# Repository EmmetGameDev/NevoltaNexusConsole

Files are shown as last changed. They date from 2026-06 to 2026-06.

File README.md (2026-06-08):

[See the build and design on YouTube!](https://www.youtube.com/watch?v=XNRuj0vmZO0)

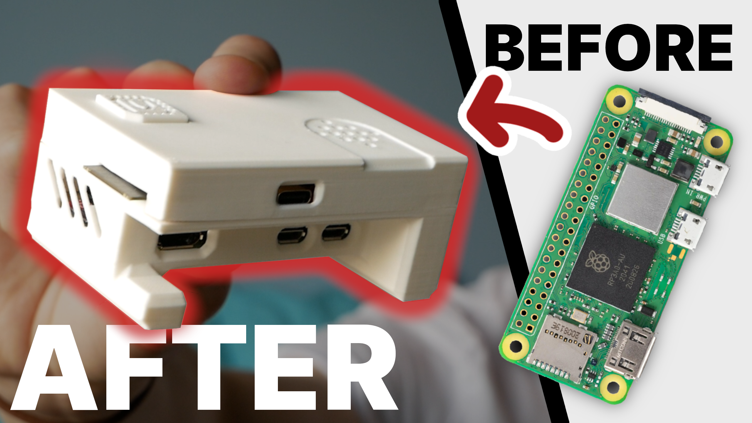
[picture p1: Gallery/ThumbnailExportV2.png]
Preview


# Nevolta Nexus

The Nexus is a **retro games console** based on the Raspberry Pi Zero 2W and the ESP32-S3. The console features:
- Custom wireless controller
- Active cooling system
- Custom PCBs
- Fully open source design

"Nevolta" is the name for my personal console line-up. **(more are coming soon!)**

# Files

- The "Printables" folder contains labeled 3D printable files for the Console unit as well as the Controller.
- The "PCBs" folder contains GERBER files, as well as KiCad project, schematic, and layout files.
- The "Firmware" folder contains two .INO files for the Console and Controller ESPs, respectively.

# Setup

## ESP32-S3 Microcontrollers
- The ESPs can be programmed when already soldered onto the board, since a data connection is present in the USB-C connector.
- Respective firmware (.INO) files are to be flashed via the [Arduino IDE](https://www.arduino.cc/en/software/)

## Raspberry Pi Zero 2W
- A generic RetroPie build is used for the Pi, which is included in the [Raspberry Pi Imager](https://www.raspberrypi.com/software/)
- Software [GPIOnext](https://github.com/mholgatem/GPIOnext) is used for GPIO button usage according to the instructions provided on the repo.
- [This tutorial](https://www.youtube.com/watch?v=BV_nVu8Be7M) is a good reference for the setup of the software.

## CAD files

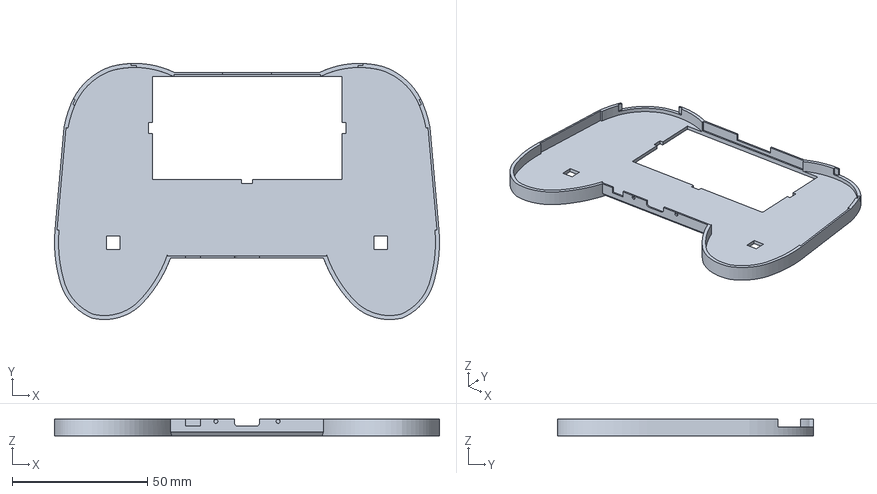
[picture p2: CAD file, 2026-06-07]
Printables/Controller_Base.3mf
142.2 x 94.6 x 6.20 mm

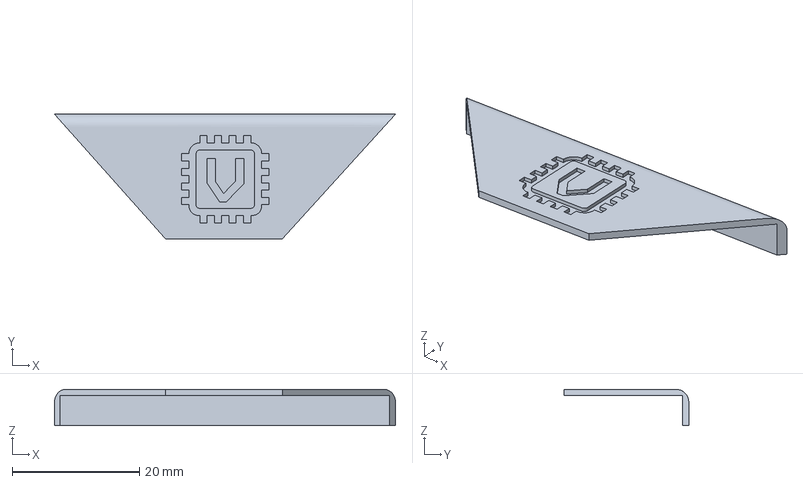
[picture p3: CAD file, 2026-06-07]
Printables/Controller_AccentPiece.3mf
53.5 x 19.6 x 5.70 mm

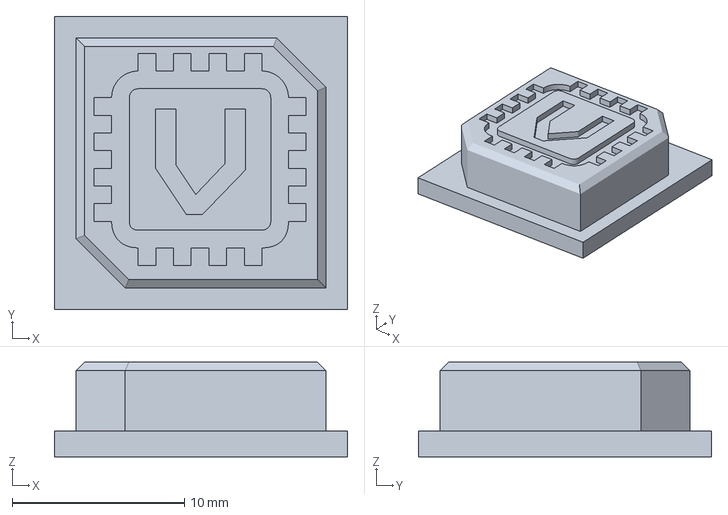
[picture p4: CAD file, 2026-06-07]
Printables/Case_Button.3mf
17.0 x 17.0 x 5.50 mm

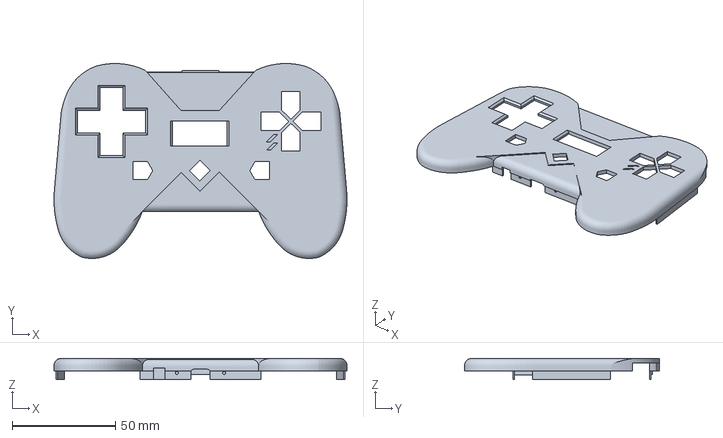
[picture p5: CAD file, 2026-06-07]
Printables/Controller_Cover.3mf
142.2 x 94.6 x 10.4 mm

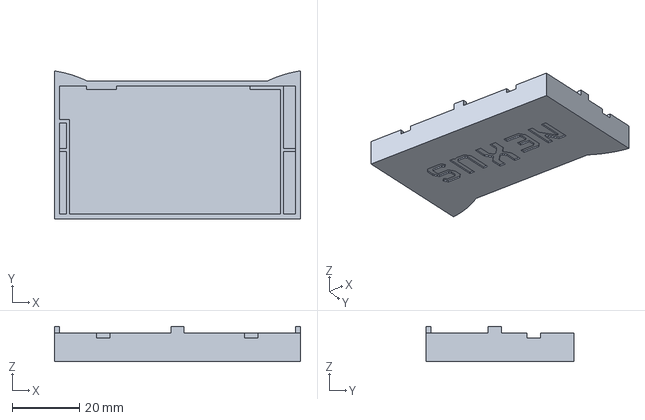
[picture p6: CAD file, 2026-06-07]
Printables/Contoller_BatteryBox.3mf
73.0 x 44.0 x 10.5 mm

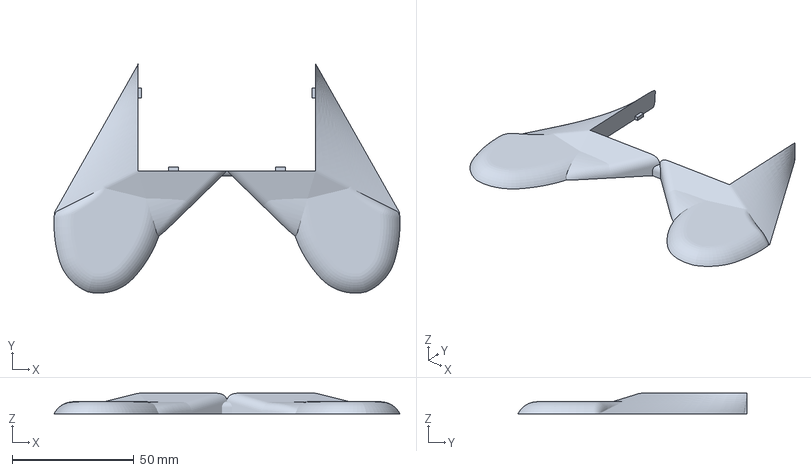
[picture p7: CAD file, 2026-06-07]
Printables/Controller_Grips.3mf
142.2 x 94.3 x 8.50 mm

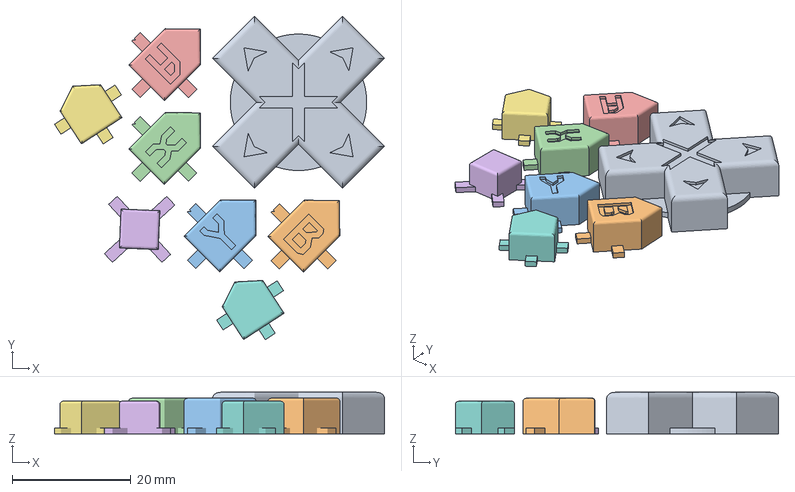
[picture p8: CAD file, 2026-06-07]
Printables/Controller_Buttons.3mf
55.6 x 54.5 x 7.00 mm
Dpad
ButtonB
ButtonY
ButtonX
ButtonA
B_System
B_Select
B_Start

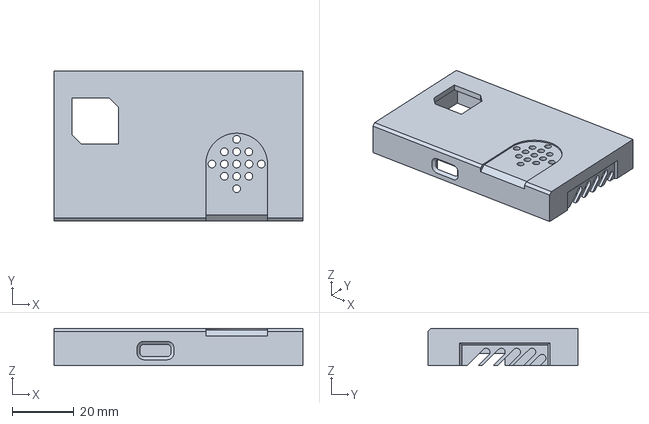
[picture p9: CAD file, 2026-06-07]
Printables/Case_TopHalf.3mf
80.7 x 48.7 x 12.0 mm

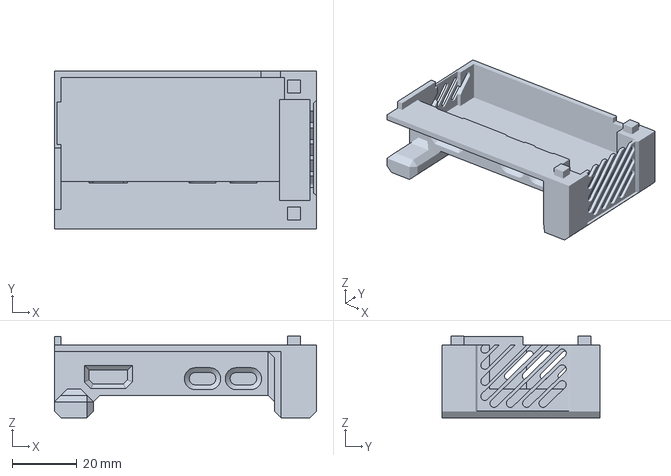
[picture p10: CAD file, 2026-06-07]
Printables/Case_BottomHalf.3mf
80.7 x 48.7 x 25.2 mm

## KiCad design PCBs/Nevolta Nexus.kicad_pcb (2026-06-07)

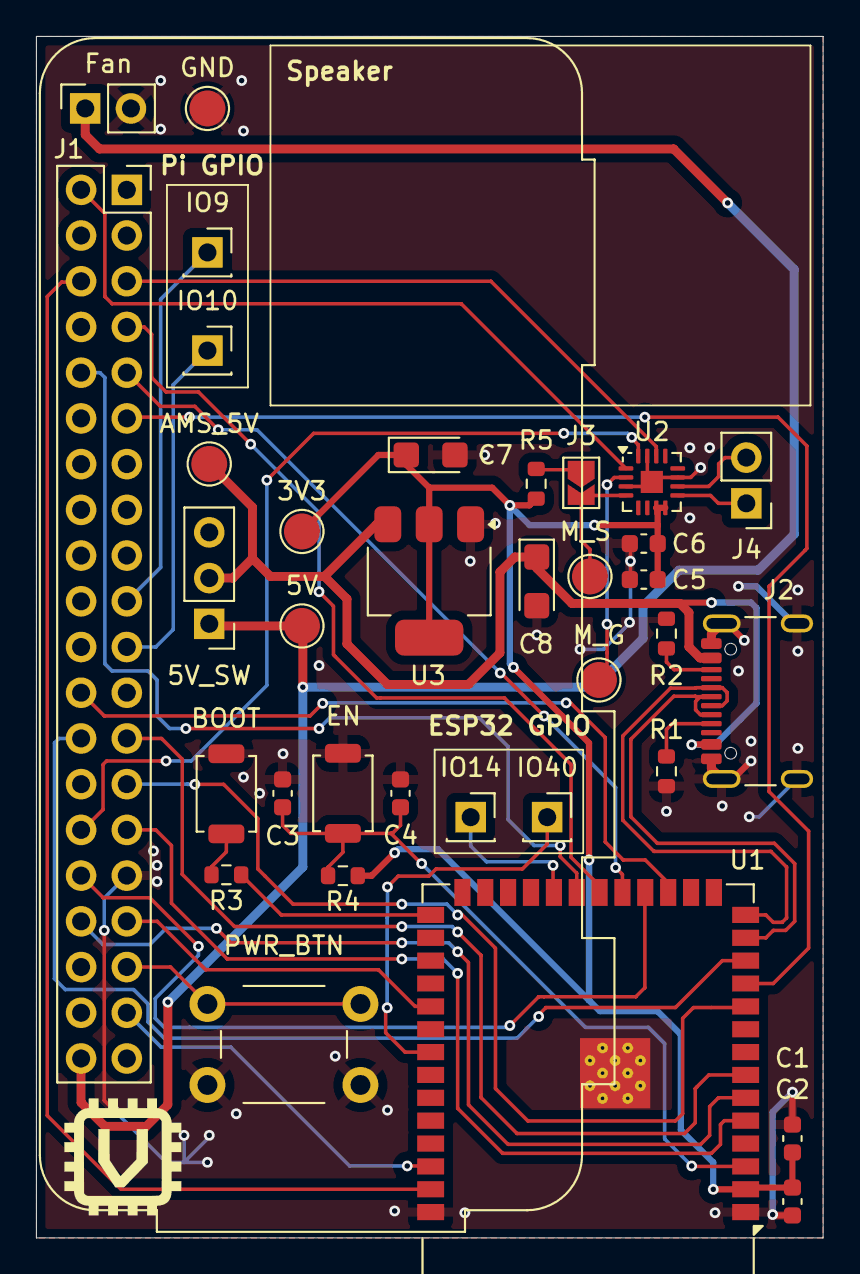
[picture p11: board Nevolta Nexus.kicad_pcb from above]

Board: 2 copper layers, 43.7 x 66.8 mm, 35 parts (0 on the bottom side), 38 nets.

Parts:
3V3: 3v3; TestPoint_Pad_D2.0mm
5V: 5V; TestPoint_Pad_D2.0mm
5V_SW: Vbus_SW; PinHeader_1x03_P2.54mm_Vertical
AMS_5V: AMS_5V; TestPoint_Pad_D2.0mm
BOOT: BOOT; SW_SPST_TS-1088-xR020
C1: 22uF; C_0603_1608Metric
C2, C4, C6: 100nF; C_0603_1608Metric
C3, C5: 10uF; C_0603_1608Metric
C7: 22uF; CP_EIA-3216-18_Kemet-A
C8: 10uF; CP_EIA-3216-18_Kemet-A
EN: EN; SW_SPST_TS-1088-xR020
Fan: Fan_Conn; PinSocket_1x02_P2.54mm_Vertical
GND: GND; TestPoint_Pad_D2.0mm
IO9: Pi_IO9; PinSocket_1x01_P2.54mm_Vertical
IO10: Pi_IO10; PinSocket_1x01_P2.54mm_Vertical
IO14: GPIO14; PinSocket_1x01_P2.54mm_Vertical
IO40: GPIO40; PinSocket_1x01_P2.54mm_Vertical
J1: Pi Zero 2W; Raspberry Pi Zero 2 W - Clear
J2: USB_C_Receptacle_USB2.0_16P; USB_C_Receptacle_GCT_USB4105-xx-A_16P_TopMnt_Horizontal
J3: SolderJumper-2_P1.3mm_Open_TrianglePad1.0x1.5mm
J4: SpeakerConn; PinHeader_1x02_P2.54mm_Vertical
M_G: MAX_GAIN; TestPoint_Pad_D2.0mm
M_S: MAX_SD; TestPoint_Pad_D2.0mm
PWR_BTN: PWR; SW_PUSH_8mm_H5mm_custom
R1, R2: 5.1k; R_0603_1608Metric
R3: 100R; R_0603_1608Metric
R4: 10k; R_0603_1608Metric
R5: 1M; R_0603_1608Metric
U1: ESP32-S3-WROOM-1
U2: MAX98357A; TQFN-16-1EP_3x3mm_P0.5mm_EP1.23x1.23mm
U3: AMS1117-3.3; SOT-223-3_TabPin2

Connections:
+3V3: 3V3.1, C1.1, C2.1, C5.2, C6.2, C7.1, R4.1, R5.1, U1.2 (3V3), U2.7 (VDD), U2.8 (VDD), U3.2 (VO)
+5V: 5V.1, 5V_SW.1 (A), Fan.1, J1.40
AMS_5V: 5V_SW.2 (B), AMS_5V.1, C8.1, J2.A4 (VBUS), J2.A9 (VBUS), J2.B4 (VBUS), J2.B9 (VBUS), U3.3 (VI)
BOOT: R3.1, U1.27 (IO0)
BTN_A: J1.37, U1.38 (IO2)
BTN_B: J1.34, U1.6 (IO6)
BTN_DOWN: J1.9, U1.19 (IO11)
BTN_L: J1.32, U1.18 (IO10)
BTN_LEFT: J1.7, U1.20 (IO12)
BTN_R: J1.6, U1.39 (IO1)
BTN_RIGHT: J1.10, U1.21 (IO13)
BTN_SELECT: J1.25, U1.7 (IO7)
BTN_START: J1.27, U1.10 (IO17)
BTN_UP: J1.11, U1.11 (IO18)
BTN_VOLD: J1.26, U1.12 (IO8)
BTN_VOLU: J1.24, U1.17 (IO9)
BTN_X: J1.33, U1.31 (IO38)
BTN_Y: J1.29, U1.5 (IO5)
Data+: J2.A6 (D+), J2.B6 (D+), U1.14 (USB_D+)
Data-: J2.A7 (D-), J2.B7 (D-), U1.13 (USB_D-)
EN: C3.1, C4.1, EN.1, R4.2, U1.3 (EN)
GND: BOOT.2, C1.2, C2.2, C3.2, C4.2, C5.1, C6.1, C7.2, C8.2, EN.2, Fan.2, GND.1, J1.31, J2.A1 (GND), J2.A12 (GND), J2.B1 (GND), J2.B12 (GND), J2.S1 (SHIELD), PWR_BTN.2, R1.2, R2.1, U1.1 (GND), U1.40 (GND), U1.41 (GND), U2.3 (GND), U2.11 (GND), U2.15 (GND), U2.17 (PAD), U3.1 (GND)
GPIO14: IO14.1, U1.22 (IO14)
GPIO40: IO40.1, U1.33 (IO40)
I2S_BCLK: J1.30, U2.16 (BCLK)
I2S_DIN: J1.2, U2.1 (DIN)
I2S_LRC: J1.5, U2.14 (LRCLK)
MAX_GAIN: M_G.1, U2.2 (GAIN_SLOT)
MAX_SD: J3.2, M_S.1, U2.4 (~SD_MODE)
unnamed: J2.A5 (CC1), R1.1
unnamed: J2.B5 (CC2), R2.2
unnamed: J3.1, R5.2
unnamed: J4.1, U2.9 (OUTP)
unnamed: J4.2, U2.10 (OUTN)
unnamed: BOOT.1, R3.2
POWER_BTN: J1.35, PWR_BTN.1
Pi_GPIO9: IO9.1, J1.19
Pi_GPIO10: IO10.1, J1.21

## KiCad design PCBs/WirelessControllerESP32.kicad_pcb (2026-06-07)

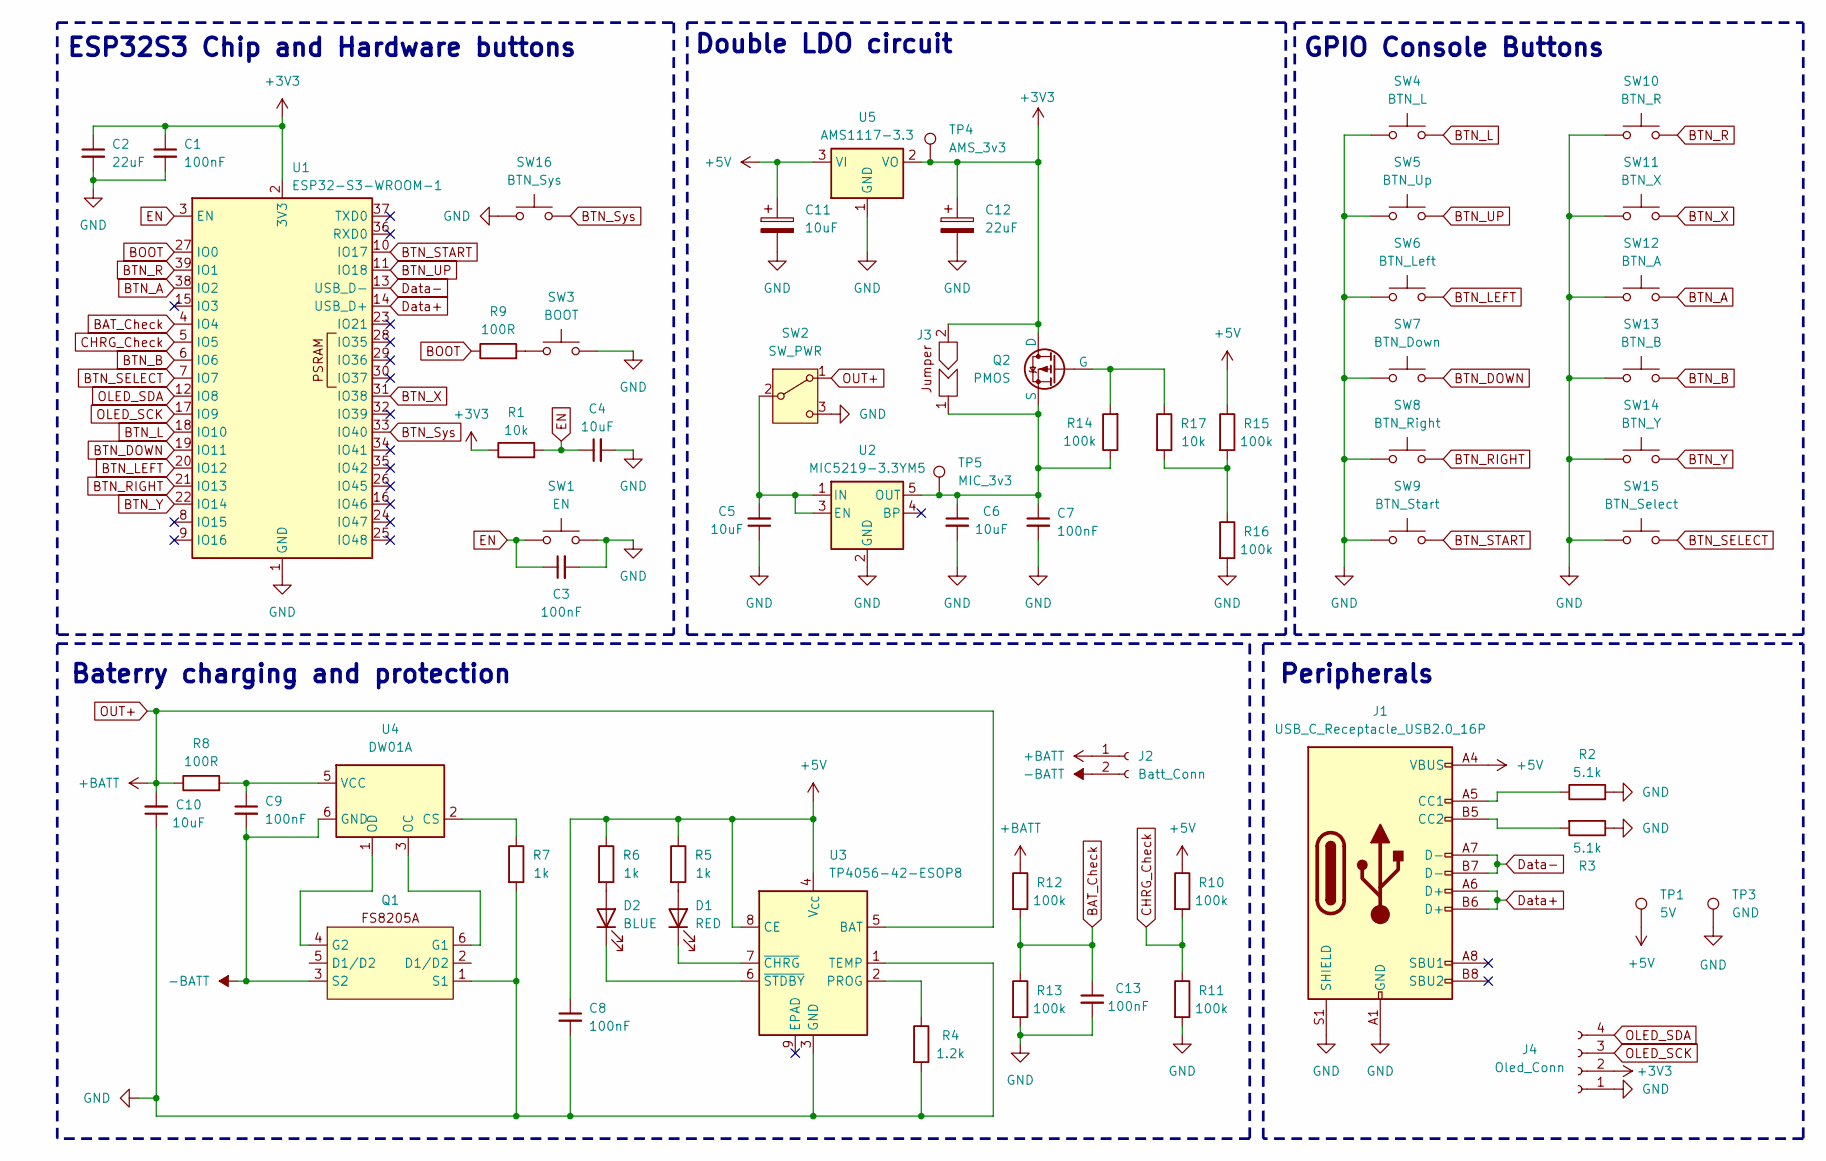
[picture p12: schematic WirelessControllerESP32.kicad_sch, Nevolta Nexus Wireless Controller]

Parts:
C1, C3, C7, C8, C9, C13: 100nF; C_0603_1608Metric
C2: 22uF; C_0603_1608Metric
C4, C5, C6, C10: 10uF; C_0603_1608Metric
C11: 10uF; CP_EIA-3216-18_Kemet-A
C12: 22uF; CP_EIA-3216-18_Kemet-A
D1: RED; LED_0603_1608Metric
D2: BLUE; LED_0603_1608Metric
J1: USB_C_Receptacle_USB2.0_16P; USB_C_Receptacle_GCT_USB4105-xx-A_16P_TopMnt_Horizontal
J2: Batt_Conn; JST_ZH_S2B-ZR-SM4A-TF_1x02-1MP_P1.50mm_Horizontal
J3: R_0603_1608Metric
J4: Oled_Conn; OLED128x32_1x04_P2.54mm_socket
Q1: SOT-23-6L_TCP
Q2: PMOS; SOT-23
R1, R17: 10k; R_0603_1608Metric
R2, R3: 5.1k; R_0603_1608Metric
R4: 1.2k; R_0603_1608Metric
R5, R6, R7: 1k; R_0603_1608Metric
R8, R9: 100R; R_0603_1608Metric
R10, R11, R12, R13, R14, R15, R16: 100k; R_0603_1608Metric
SW1: EN; SW_SPST_TS-1088-xR020
SW2: SW_PWR; PinSocket_1x03_P2.54mm_Vertical
SW3: BOOT; SW_SPST_TS-1088-xR020
SW4: BTN_L; TS-1224VW
SW5: BTN_Up; SW_PUSH_8mm_H5mm_custom
SW6: BTN_Left; SW_PUSH_8mm_H5mm_custom
SW7: BTN_Down; SW_PUSH_8mm_H5mm_custom
SW8: BTN_Right; SW_PUSH_8mm_H5mm_custom
SW9: BTN_Start; SW_PUSH_8mm_H5mm_custom
SW10: BTN_R; TS-1224VW
SW11: BTN_X; SW_PUSH_8mm_H5mm_custom
SW12: BTN_A; SW_PUSH_8mm_H5mm_custom
SW13: BTN_B; SW_PUSH_8mm_H5mm_custom
SW14: BTN_Y; SW_PUSH_8mm_H5mm_custom
SW15: BTN_Select; SW_PUSH_8mm_H5mm_custom
SW16: BTN_Sys; SW_PUSH_8mm_H5mm_custom
TP1: 5V; TestPoint_Pad_D2.0mm
TP3: GND; TestPoint_Pad_D2.0mm
TP4: AMS_3v3; TestPoint_Pad_D2.0mm
TP5: MIC_3v3; TestPoint_Pad_D2.0mm
U1: ESP32-S3-WROOM-1
U2: MIC5219-3.3YM5; SOT-23-5
U3: TP4056-42-ESOP8; SOIC-8-1EP_3.9x4.9mm_P1.27mm_EP2.41x3.3mm_ThermalVias
U4: DW01A; SOT-23-6
U5: AMS1117-3.3; SOT-223-3_TabPin2

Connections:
+3V3: C1.1, C2.1, C12.1, J3.2, J4.2, Q2.1 (D), R1.1, TP4.1, U1.2 (3V3), U5.2 (VO)
+5V: C8.1, C11.1, J1.A4 (VBUS), J1.A9 (VBUS), J1.B4 (VBUS), J1.B9 (VBUS), R5.1, R6.1, R10.1, R15.1, TP1.1, U3.4 (V_{CC}), U3.8 (CE), U5.3 (VI)
-BATT: C9.2, J2.2, Q1.3 (S2), U4.6 (GND)
BAT_Check: C13.1, R12.2, R13.1, U1.4 (IO4)
BOOT: R9.1, U1.27 (IO0)
BTN_A: SW12.2, U1.38 (IO2)
BTN_B: SW13.2, U1.6 (IO6)
BTN_DOWN: SW7.2, U1.19 (IO11)
BTN_L: SW4.2, U1.18 (IO10)
BTN_LEFT: SW6.2, U1.20 (IO12)
BTN_R: SW10.2, U1.39 (IO1)
BTN_RIGHT: SW8.2, U1.21 (IO13)
BTN_SELECT: SW15.2, U1.7 (IO7)
BTN_START: SW9.2, U1.10 (IO17)
BTN_Sys: SW16.2, U1.33 (IO40)
BTN_UP: SW5.2, U1.11 (IO18)
BTN_X: SW11.2, U1.31 (IO38)
BTN_Y: SW14.2, U1.22 (IO14)
CHRG_Check: R10.2, R11.1, U1.5 (IO5)
Data+: J1.A6 (D+), J1.B6 (D+), U1.14 (USB_D+)
Data-: J1.A7 (D-), J1.B7 (D-), U1.13 (USB_D-)
EN: C3.1, C4.1, R1.2, SW1.1, U1.3 (EN)
GND: C1.2, C2.2, C3.2, C4.2, C5.1, C6.2, C7.2, C8.2, C10.1, C11.2, C12.2, C13.2, J1.A1 (GND), J1.A12 (GND), J1.B1 (GND), J1.B12 (GND), J1.S1 (SHIELD), J4.1, Q1.1 (S1), R2.2, R3.1, R4.2, R7.2, R11.2, R13.2, R16.2, SW1.2, SW2.3 (C), SW3.2, SW4.1, SW5.1, SW6.1, SW7.1, SW8.1, SW9.1, SW10.1, SW11.1, SW12.1, SW13.1, SW14.1, SW15.1, SW16.1, TP3.1, U1.1 (GND), U1.40 (GND), U1.41 (GND), U2.2 (GND), U3.1 (TEMP), U3.3 (GND), U5.1 (GND)
unnamed: D1.2 (A), R5.2
unnamed: D1.1 (K), U3.7 (~CHRG)
unnamed: D2.2 (A), R6.2
unnamed: D2.1 (K), U3.6 (~STDBY)
unnamed: J1.A5 (CC1), R2.1
unnamed: J1.B5 (CC2), R3.2
unnamed: Q1.6 (G1), U4.3 (OC)
unnamed: Q1.4 (G2), U4.1 (OD)
unnamed: Q2.2 (G), R14.2, R17.1
unnamed: C6.1, C7.1, J3.1, Q2.3 (S), R14.1, TP5.1, U2.5 (OUT)
unnamed: R9.2, SW3.1
unnamed: R15.2, R16.1, R17.2
unnamed: C5.2, SW2.2 (B), U2.1 (IN), U2.3 (EN)
unnamed: R4.1, U3.2 (PROG)
unnamed: R7.1, U4.2 (CS)
unnamed: C9.1, R8.2, U4.5 (VCC)
OLED_SCK: J4.3, U1.17 (IO9)
OLED_SDA: J4.4, U1.12 (IO8)
OUT+: C10.2, J2.1, R8.1, R12.1, SW2.1 (A), U3.5 (BAT)

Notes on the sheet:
Peripherals
ESP32S3 Chip and Hardware buttons
GPIO Console Buttons
Double LDO circuit
Baterry charging and protection

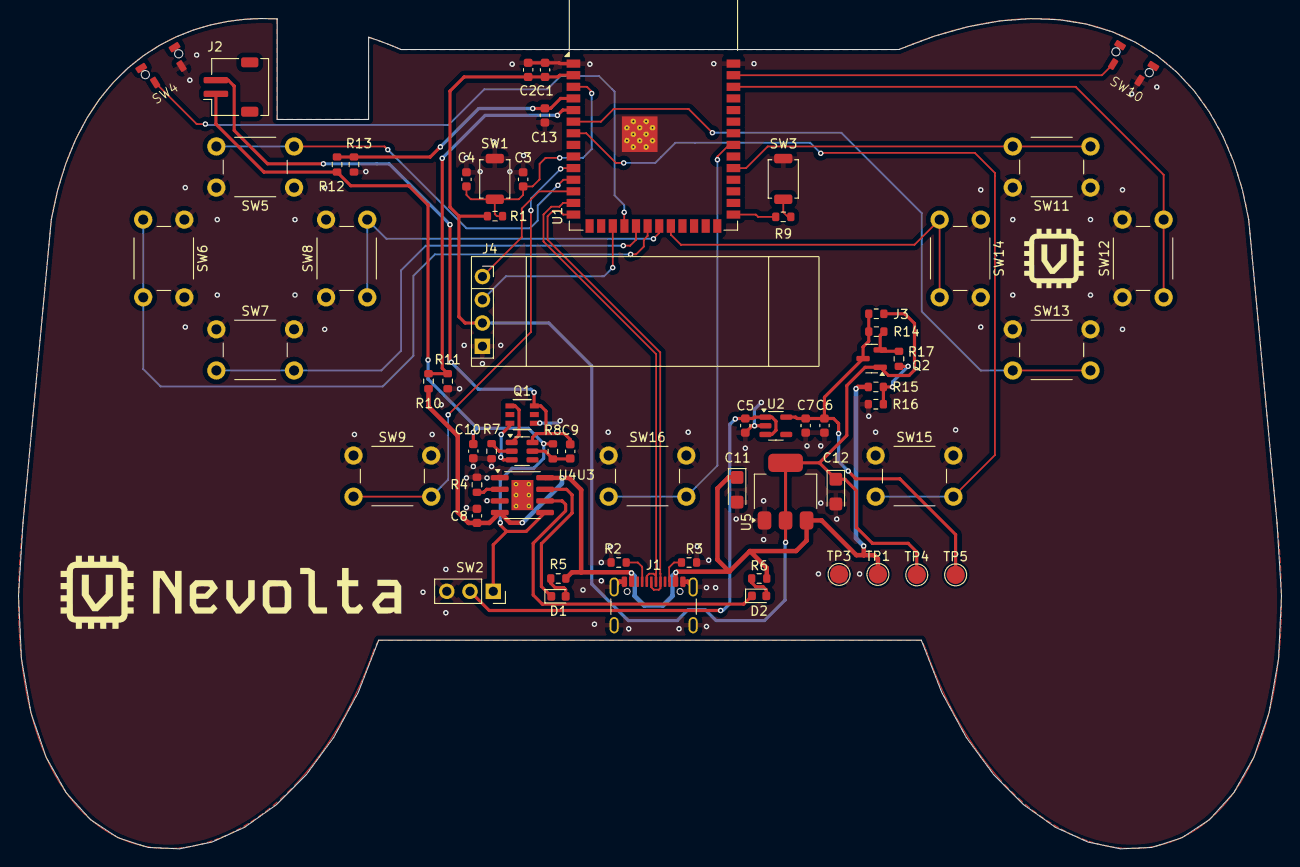
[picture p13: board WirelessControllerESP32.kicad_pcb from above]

Board: 2 copper layers, 138.1 x 90.8 mm, 63 parts (0 on the bottom side), 42 nets.

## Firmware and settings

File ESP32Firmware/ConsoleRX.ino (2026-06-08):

#include <esp_now.h>
#include <WiFi.h>
#include <esp_wifi.h>

typedef struct struct_message {
  char a[32];
  int b;
  float c;
  bool d;
} struct_message;
struct_message myData;

int btn_L_Pin = 10;
int btn_Up_Pin = 18;
int btn_Right_Pin = 13;
int btn_Down_Pin = 11;
int btn_Left_Pin = 12;
int btn_Start_Pin = 17;
int btn_Select_Pin = 7;
int btn_X_Pin = 38;
int btn_A_Pin = 2;
int btn_B_Pin = 6;
int btn_Y_Pin = 5;
int btn_R_Pin = 1;

int btn_VolD_Pin = 8;
int btn_VolU_Pin = 9;


void OnDataRecv(const uint8_t * mac, const uint8_t *incomingData, int len) {
  memcpy(&myData, incomingData, sizeof(myData));
  /*Serial.print("Bytes received: ");
  Serial.println(len);
  Serial.print("Int: ");
  Serial.println(myData.b);
  Serial.print("Bool: ");
  Serial.println(myData.d);
  Serial.println();*/
  buttonPressed(myData.b, myData.d);
}

void readMacAddress(){
  uint8_t baseMac[6];
  esp_err_t ret = esp_wifi_get_mac(WIFI_IF_STA, baseMac);
  if (ret == ESP_OK) {
    Serial.printf("%02x:%02x:%02x:%02x:%02x:%02x\n",
                  baseMac[0], baseMac[1], baseMac[2],
                  baseMac[3], baseMac[4], baseMac[5]);
  } else {
    Serial.println("Failed to read MAC address");
  }
}

void buttonPressed(int buttonID, bool doIPress){
  uint8_t pressAction;
  if(doIPress == true){
    Serial.print("Button pressed: ");
    pressAction = LOW;
  }else{
    Serial.print("Button unpressed: ");
    pressAction = HIGH;
  }
  switch (buttonID) {
    case 0:
      digitalWrite(btn_L_Pin, pressAction);
      break;
    case 1:
      digitalWrite(btn_Up_Pin, pressAction);
      break;
    case 2:
      digitalWrite(btn_Right_Pin, pressAction);
      break;
    case 3:
      digitalWrite(btn_Down_Pin, pressAction);
      break;
    case 4:
      digitalWrite(btn_Left_Pin, pressAction);
      break;
    case 5:
      digitalWrite(btn_Start_Pin, pressAction);
      break;
    case 6:
      digitalWrite(btn_Select_Pin, pressAction);
      break;
    case 7:
      digitalWrite(btn_X_Pin, pressAction);
      break;
    case 8:
      digitalWrite(btn_A_Pin, pressAction);
      break;
    case 9:
      digitalWrite(btn_B_Pin, pressAction);
      break;
    case 10:
      digitalWrite(btn_Y_Pin, pressAction);
      break;
    case 11:
      digitalWrite(btn_R_Pin, pressAction);
      break;
    case 15:
      digitalWrite(btn_VolD_Pin, pressAction);
      break;
    case 16:
      digitalWrite(btn_VolU_Pin, pressAction);
      break;
    default:
      break;
  }
  Serial.print("\n");
}

void setup(){
  Serial.begin(115200);

  WiFi.mode(WIFI_STA);
  WiFi.disconnect();

  Serial.println(WiFi.macAddress());

  if (esp_now_init() != ESP_OK){
    Serial.println("RX ESPNOW FAIL");
    return;
  }

  esp_now_register_recv_cb(OnDataRecv);

  Serial.println("RX READY");
  digitalWrite(btn_L_Pin, HIGH);
  pinMode(btn_L_Pin, OUTPUT);

  digitalWrite(btn_Up_Pin, HIGH);
  pinMode(btn_Up_Pin, OUTPUT);

  digitalWrite(btn_Right_Pin, HIGH);
  pinMode(btn_Right_Pin, OUTPUT);

  digitalWrite(btn_Down_Pin, HIGH);
  pinMode(btn_Down_Pin, OUTPUT);

  digitalWrite(btn_Left_Pin, HIGH);
  pinMode(btn_Left_Pin, OUTPUT);

  digitalWrite(btn_Start_Pin, HIGH);
  pinMode(btn_Start_Pin, OUTPUT);

  digitalWrite(btn_Select_Pin, HIGH);
  pinMode(btn_Select_Pin, OUTPUT);

  digitalWrite(btn_X_Pin, HIGH);
  pinMode(btn_X_Pin, OUTPUT);

  digitalWrite(btn_A_Pin, HIGH);
  pinMode(btn_A_Pin, OUTPUT);

  digitalWrite(btn_B_Pin, HIGH);
  pinMode(btn_B_Pin, OUTPUT);

  digitalWrite(btn_Y_Pin, HIGH);
  pinMode(btn_Y_Pin, OUTPUT);

  digitalWrite(btn_R_Pin, HIGH);
  pinMode(btn_R_Pin, OUTPUT);

  digitalWrite(btn_VolD_Pin, HIGH);
  pinMode(btn_VolD_Pin, OUTPUT);
  
  digitalWrite(btn_VolU_Pin, HIGH);
  pinMode(btn_VolU_Pin, OUTPUT);

  Serial.println("Buttons READY");
}

void loop(){

}

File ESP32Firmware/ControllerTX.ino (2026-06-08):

#include <esp_now.h>
#include <WiFi.h>
#include "esp_wifi.h"
#include <Wire.h>
#include <SPI.h>
#include <Adafruit_GFX.h>
#include <Adafruit_SSD1306.h>

#define SCREEN_WIDTH 128
#define SCREEN_HEIGHT 32
#define OLED_RESET 4
Adafruit_SSD1306 display(SCREEN_WIDTH, SCREEN_HEIGHT, &Wire, OLED_RESET);

struct button{
  int pin;
  int buttonLastState;
};

const int systemButton = 40;
int currentSystemMode = 0;
/*
System modes:
0 - controller mode
1 - system control mode
2 - controller mode, display off
*/
int systemButtonLastState = HIGH;

const unsigned long interval = 10000; // 10 seconds
unsigned long previousMillis = 0;
const int batPin = 4;

const unsigned long intervalCharge = 3000; // 3 seconds
unsigned long previousMillisCharge = 0;
const int chargePin = 5;
int lastChargeState = LOW;
bool isCharging = false;
bool wasCharging = false;

/* 
Buttons:
0. L
1. Up
2. Right
3. Down
4. Left
5. Start
6. Select
7. X
8. A
9. B
10. Y
11. R

Software-based:
15. VolD
16. VolU
*/
const int buttonCount = 12;
button buttonsList[buttonCount];

uint8_t broadcastAddress[] = {0x00, 0x01, 0x02, 0x03, 0x04, 0x05}; // INSERT YOUR MAC ADRESS HERE!!!

typedef struct struct_message {
  char a[32];
  int b;
  float c;
  bool d;
} struct_message;
struct_message myData;
esp_now_peer_info_t peerInfo;

void OnDataSent(const uint8_t *mac_addr, esp_now_send_status_t status) {
  Serial.print("\r\nLast Packet Send Status:\t");
  Serial.println(status == ESP_NOW_SEND_SUCCESS ? "Delivery Success" : "Delivery Fail");
}

void readMacAddress(){
  uint8_t baseMac[6];
  esp_err_t ret = esp_wifi_get_mac(WIFI_IF_STA, baseMac);
  if (ret == ESP_OK) {
    Serial.printf("%02x:%02x:%02x:%02x:%02x:%02x\n",
                  baseMac[0], baseMac[1], baseMac[2],
                  baseMac[3], baseMac[4], baseMac[5]);
  } else {
    Serial.println("Failed to read MAC address");
  }
}

void setup(){
  buttonsList[0].pin = 10;
  buttonsList[1].pin = 18;
  buttonsList[2].pin = 13;
  buttonsList[3].pin = 11;
  buttonsList[4].pin = 12;
  buttonsList[5].pin = 17;
  buttonsList[6].pin = 7;
  buttonsList[7].pin = 38;
  buttonsList[8].pin = 2;
  buttonsList[9].pin = 6;
  buttonsList[10].pin = 14;
  buttonsList[11].pin = 1;
  for (int i = 0; i < buttonCount; i++) {
    pinMode(buttonsList[i].pin, INPUT_PULLUP);
    buttonsList[i].buttonLastState = HIGH;
  }
  pinMode(systemButton, INPUT_PULLUP);
  Serial.begin(115200);
 
  // Set device as a Wi-Fi Station
  WiFi.mode(WIFI_STA);

  // Init ESP-NOW
  if (esp_now_init() != ESP_OK) {
    Serial.println("Error initializing ESP-NOW");
    return;
  }

  // Once ESPNow is successfully Init, we will register for Send CB to
  // get the status of Trasnmitted packet
  esp_now_register_send_cb(esp_now_send_cb_t(OnDataSent));
  
  // Add peer LAST
  esp_now_peer_info_t peerInfo;
  memset(&peerInfo, 0, sizeof(peerInfo));

  memcpy(peerInfo.peer_addr, broadcastAddress, 6);
  peerInfo.channel = 0;   // Let ESP choose channel
  peerInfo.encrypt = false;

  if (esp_now_add_peer(&peerInfo) != ESP_OK) {
    Serial.println("Peer add FAIL");
    return;
  }

  Serial.println("TX READY");

  Wire.begin();
  display.begin(SSD1306_SWITCHCAPVCC, 0x3C);

  display.clearDisplay();
  display.setTextColor(WHITE);
  display.setTextSize(2);
  display.setCursor(12, 15);
  String neuro = "Nevolta";
  for(int i = 0; i < neuro.length(); i++){
    display.print(neuro[i]);
    display.display();
    delay(150);
  }
  delay(1000);
}

void displayAnimation(){
  display.clearDisplay();
  display.setTextColor(WHITE);
  display.setTextSize(2);
  display.setCursor(12, 15);
  switch (currentSystemMode) {
    case 0:{
      String contr = "Controller";
      for(int i = 0; i < contr.length(); i++){
        display.print(contr[i]);
        display.display();
        delay(150);
      }
      break;
    }
    case 1:{
      String sett = "Settings";
      for(int i = 0; i < sett.length(); i++){
        display.print(sett[i]);
        display.display();
        delay(150);
      }
      break;
    }
    case 2:{
      String disp = "Display off";
      for(int i = 0; i < disp.length(); i++){
        display.print(disp[i]);
        display.display();
        delay(150);
      }
      delay(1000);
      display.clearDisplay();
      display.display();
      break;
    }
    default:
      break;
  }
}

void chargingAnim(){
  display.clearDisplay();
  display.setTextColor(WHITE);
  display.setTextSize(2);
  display.setCursor(12, 15);
  String neuro = "Charging";
  for(int i = 0; i < neuro.length(); i++){
    display.print(neuro[i]);
    display.display();
    delay(150);
  }
  neuro = "...";
  for (int j = 0; j < 3; j++) {
    for(int i = 0; i < neuro.length(); i++){
      display.print(neuro[i]);
      display.display();
      delay(150);
    }
  }
}
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

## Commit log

2026-06-07 PCB files and Printables Added
    [Case_BottomHalf.3mf, Case_Button.3mf, Case_TopHalf.3mf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]
2026-06-08 ESP32 firmware added
